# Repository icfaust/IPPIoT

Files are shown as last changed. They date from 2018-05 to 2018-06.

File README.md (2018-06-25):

# IPPIoT
ESP8266 native Non-OS SDK 7-segment JSON number display

This is the necessary documentation for someone to collect the necessary components and compile the right code for
their very own web JSON reader.  Its pretty basic with a hardcoded wifi and website to access for the JSON. 

The components should all work well together, using the CATIA files, EAGLE files, and list of components to create
the device.  If you end up trying to build one, let me know!!!!!

The code does require a successfully installed pfaclon esp-open-sdk installation.  The makefile should work pretty straight-forwardly on a Ubuntu or Linux distro (thats what I used).

You can go over to my personal website for a more in-depth explanation of the design process with photos.

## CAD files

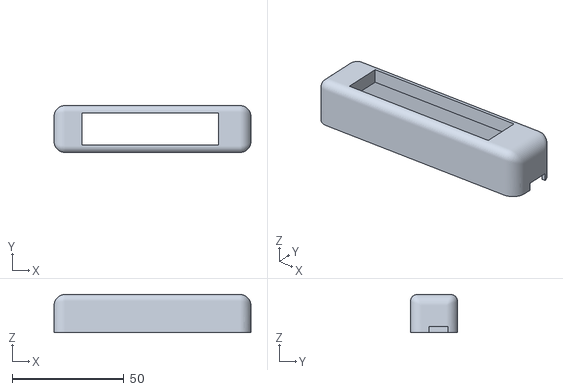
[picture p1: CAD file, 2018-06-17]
CATIA/Top_Housing.stl
88.0 x 21.0 x 17.0

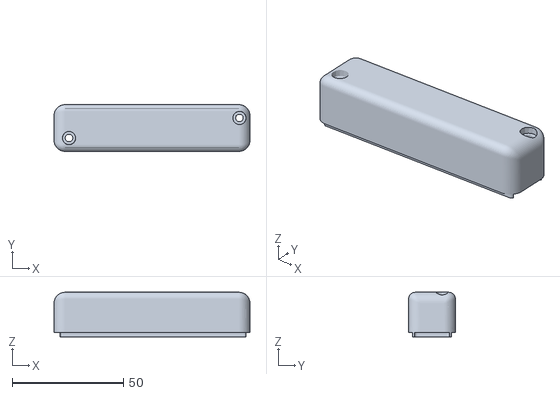
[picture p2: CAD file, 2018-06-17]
CATIA/Back_Housing.stl
88.0 x 21.0 x 20.0

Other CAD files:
CATIA/Back_Housing.CATPart
CATIA/Top_Housing.CATPart

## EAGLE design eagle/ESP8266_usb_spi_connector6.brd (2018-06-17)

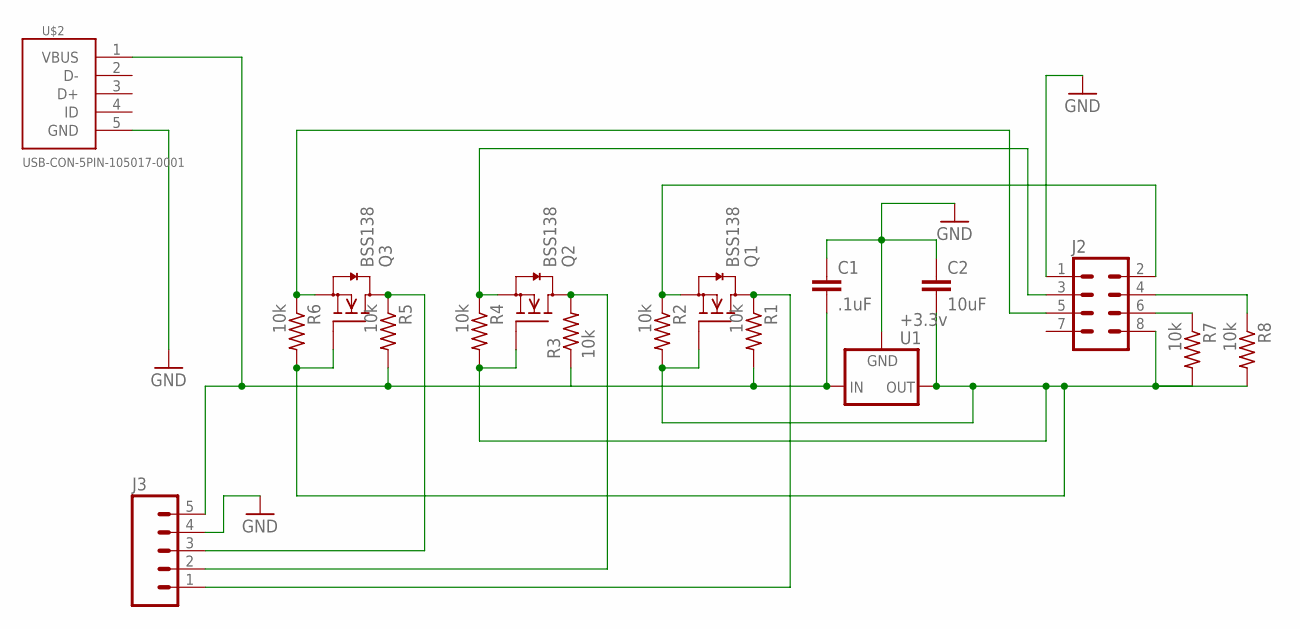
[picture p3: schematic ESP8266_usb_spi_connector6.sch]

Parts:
C1: .1uF; 1206
C2: 10uF; 1206
J2: M04X2; 2X4
J3: M05PTH; 1X05
Q1, Q2, Q3: BSS138; SOT23
R1, R2, R3, R4, R5, R6, R7, R8: 10k; M1206
U1: +3.3v; TO-252
U$2: USB-CON-5PIN-105017-0001; USB-MICRO-MOLEX-105017-0001

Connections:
GND: C1.1, C2.1, J2.1, J3.4, U1.3 (GND), U$2.5 (GND)
unnamed: J3.3, Q3.3 (D), R5.1
unnamed: J2.3, Q2.2 (S), R4.1
unnamed: C2.2, J2.8, Q1.1 (G), Q2.1 (G), Q3.1 (G), R2.2, R4.2, R6.2, R7.2, R8.2, U1.2 (OUT)
unnamed: J3.2, Q2.3 (D), R3.2
unnamed: J3.1, Q1.3 (D), R1.1
unnamed: J2.5, Q3.2 (S), R6.1
unnamed: J2.2, Q1.2 (S), R2.1
unnamed: C1.2, J3.5, R1.2, R3.1, R5.2, U1.1 (IN), U$2.1 (VBUS)
unnamed: J2.6, R7.1
unnamed: J2.4, R8.1

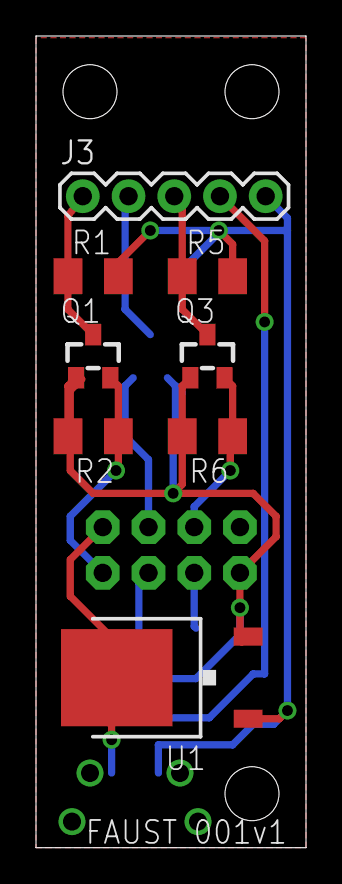
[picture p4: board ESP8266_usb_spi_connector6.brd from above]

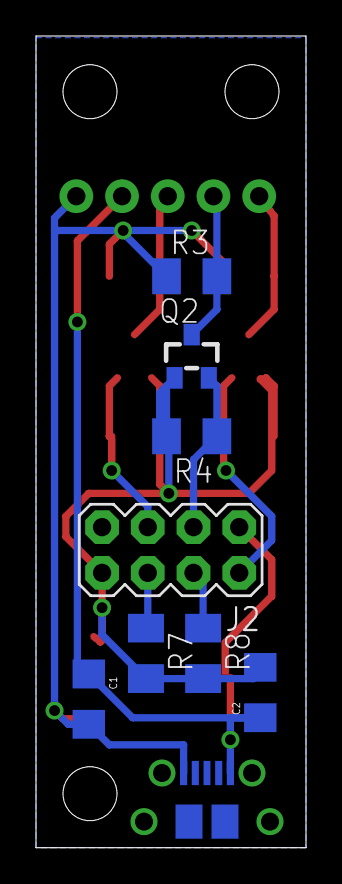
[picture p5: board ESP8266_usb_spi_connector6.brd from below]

Board: 2 copper layers, 15.0 x 45.1 mm, 17 parts (9 on the bottom side), 11 nets.

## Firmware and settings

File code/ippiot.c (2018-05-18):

#include "ets_sys.h"
#include "osapi.h"
#include "gpio.h"
#include "os_type.h"
#include "user_interface.h"
#include "jsonparse.h"

#include "max7221.h"
#include "httpclient.h"

static volatile os_timer_t polling_timer;
static volatile os_timer_t disp_timer;

int inp = 0x01; //intensity metric
int shot = 0;
int hysteresis = 1;

struct jsonparse_state JSONdata;

void ICACHE_FLASH_ATTR dweet_callback(char * response_body, int http_status, char * response_headers, int body_size)
{
  int json_type;
  char string[128];
  int flag = 0;
  jsonparse_setup(&JSONdata, response_body, body_size);
  json_type = jsonparse_next(&JSONdata);

  while(json_type && !flag)
  {
    if(json_type == JSON_TYPE_PAIR_NAME)
      {
	jsonparse_copy_value(&JSONdata, string, 128);
	if(!strcmp("shot", string))
	  {
	    flag = 1;
	  }
      }
    json_type = jsonparse_next(&JSONdata);
  }
  
  if(flag && (json_type == JSON_TYPE_INT || json_type == JSON_TYPE_NUMBER))
    {
      shot = jsonparse_get_value_as_int(&JSONdata);
    }
  else
    {
      shot = 0;
    }
}
  
void ICACHE_FLASH_ATTR scan_intensity(void *args)
{
  printf_max(MAX_INTS,inp);
  //intensity(inp);  
  inp = inp + 1;
  if(inp > 0x0F)
    {
      inp = 0x00;
    }
}

void ICACHE_FLASH_ATTR heartbeat(void *arg)
{
  //function to minimally show that the device is on
  if(inp != 0)
    {
      printf_max(0x01,0x80);
      inp = 0;
    }
  else
    {
      printf_max(0x01,0x00);
      inp = 1;
    }
}

void ICACHE_FLASH_ATTR startup( void *arg)
{
  int i=8;

  if(inp <= 0x01 || inp > 0x40)
  {
    inp = 0x40;
  }
    //function to minimally show that the device is on
  for(;i;i--)
    {
      printf_max(i,inp);
    }
  inp = inp >> 1;
}

void ICACHE_FLASH_ATTR polling(void *arg){

  http_get("https://dweet.io/get/latest/dweet/for/AUGSIF","",dweet_callback);

  if(shot != hysteresis)
    {

      os_timer_disarm(&disp_timer);
      os_timer_disarm(&polling_timer);
      
      if(shot == 0)
	{
	  clear_max();
	  //intensity(0x0F);
	  printf_max(MAX_INTS,0x0F);
	  
	  os_timer_setfn(&disp_timer, (os_timer_func_t *)heartbeat, NULL);
	  os_timer_arm(&disp_timer, 1000, 1);
	  
	  os_timer_setfn(&polling_timer, (os_timer_func_t *)polling, NULL);
	  os_timer_arm(&polling_timer, 600000, 1); // only check every 10 minutes if data in unavailable
	  
	}
      else if(shot < 0)
	{
	  disp_shot_text();
	  //start timer
	  os_timer_setfn(&disp_timer, (os_timer_func_t *)scan_intensity, NULL);
	  os_timer_arm(&disp_timer, 100, 1);
	  
	  os_timer_setfn(&polling_timer, (os_timer_func_t *)polling, NULL);
	  os_timer_arm(&polling_timer, 5000, 1); // check every 5 seconds while in shot cycle
	  
	}
      else
	{
	  //display shot
	  //intensity(0x0F);
	  printf_max(MAX_INTS,0x0F);
	  printf_max_int(shot);
	  
	  os_timer_setfn(&polling_timer, (os_timer_func_t *)polling, NULL);
	  os_timer_arm(&polling_timer, 20000, 1); // check every 20 seconds during runday
	}

      hysteresis = shot;
    }
}

void ICACHE_FLASH_ATTR wifi_handle_event_cb(System_Event_t *evt)
{
  
  switch (evt->event) {
  case EVENT_STAMODE_CONNECTED:
    os_timer_disarm(&disp_timer);
    os_timer_disarm(&polling_timer);
    
    clear_max();
    //intensity(0x0F);
    printf_max(MAX_INTS,0x0F);

    os_timer_setfn(&disp_timer, (os_timer_func_t *)heartbeat, NULL);
    os_timer_arm(&disp_timer, 1000, 1);
    break;
    
  case EVENT_STAMODE_DISCONNECTED:
    os_timer_disarm(&disp_timer);
    os_timer_disarm(&polling_timer);
    
    os_timer_setfn(&disp_timer, (os_timer_func_t *)startup, NULL);
    os_timer_arm(&disp_timer, 100, 1);
    break;
    
  case EVENT_STAMODE_AUTHMODE_CHANGE:
    os_timer_disarm(&disp_timer);
    os_timer_disarm(&polling_timer);
    
    os_timer_setfn(&disp_timer, (os_timer_func_t *)startup, NULL);
    os_timer_arm(&disp_timer, 100, 1);
    break;
    
  case EVENT_STAMODE_GOT_IP:    
    //os_timer_disarm(&polling_timer);
    //os_timer_setfn(&polling_timer, (os_timer_func_t *)polling, NULL);
    //os_timer_arm(&polling_timer, 20000, 1);
    polling(NULL);
    break;
    
  default:
    break;
  }
}

void ICACHE_FLASH_ATTR user_init()
{  
  struct station_config wifi_config;
  // init gpio subsytem
  gpio_init();

  // configure UART TXD to be GPIO1, set as output
  PIN_FUNC_SELECT(PERIPHS_IO_MUX_U0TXD_U, FUNC_GPIO1); 
  /*gpio_output_set(0, BIT2, BIT2, 0);
  gpio_output_set(0, BIT1, BIT1, 0); //OFF
  gpio_output_set(0, BIT0, BIT0, 0);*/

  //gpio_output_set(BIT2, 0, BIT2, 0);
  //gpio_output_set(BIT1, 0, BIT1, 0); //ON
  //gpio_output_set(BIT0, 0, BIT0, 0);
  
  max_init(NULL);

  //printf_max(0x01,0xFF);
  // startup no wifi display animation
  os_timer_disarm(&disp_timer);
  os_timer_setfn(&disp_timer, (os_timer_func_t *)startup, NULL);
  os_timer_arm(&disp_timer, 100, 1);

  wifi_set_opmode(STATION_MODE);
  // set station configuration, save to flash
  os_memset(&wifi_config, 0, sizeof(wifi_config));
  os_memcpy(&wifi_config.ssid, "IPP Guests", os_strlen("IPP Guests"));
  os_memcpy(&wifi_config.password, "", os_strlen(""));
  wifi_station_set_config(&wifi_config);
  
  wifi_set_event_handler_cb(wifi_handle_event_cb);
}

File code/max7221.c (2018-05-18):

#include "ets_sys.h"
#include "osapi.h"
#include "gpio.h"
#include "os_type.h"

#include "max7221.h"

void ICACHE_FLASH_ATTR bit_bang_SPI(int val){
  /* this takes a one byte unsigned char containing two hex values
  // and writes it out to GPIO 
  */
  //unsigned char val = 0xA9;
  
  int test = 0x80;
  int i=0;
  for(;i<8;i++) {
    
    if (val & test)
    {    
    gpio_output_set(BIT0, 0, BIT0, 0); //DIN HIGH (ON)
    }  
    else
    {  
    gpio_output_set(0, BIT0, BIT0, 0); //DIN LOW (OFF)
    }
    os_delay_us(10);


    gpio_output_set(0, BIT1, BIT1, 0); //CLK LOW (OFF)
    os_delay_us(10);    
    gpio_output_set(BIT1, 0, BIT1, 0); //CLK HIGH (ON)
    os_delay_us(10);
    
    val = val << 1;
  }
}


void ICACHE_FLASH_ATTR printf_max(int word1, int word2){
  gpio_output_set(0, BIT2, BIT2, 0); //CS LOW (OFF)
  bit_bang_SPI(word1);
  bit_bang_SPI(word2);
  gpio_output_set(BIT2, 0, BIT2, 0); //CS HIGH (ON) LATCH DATA
  os_delay_us(10);
}


void ICACHE_FLASH_ATTR max_init(void *args){

  os_delay_us(5000);
  printf_max(MAX_DISP, 0xFE); //display normal
  printf_max(MAX_SHUT, 0x01); //shutdown normal
  printf_max(MAX_DECO, 0x00); // put everything in individual control
  printf_max(MAX_SCAN, 0x0F); //scan limit all digits
  //intensity(0x0F); // set high intensity
  printf_max(MAX_INTS, 0x0F);
  clear_max();
  os_delay_us(5000); 
}


void ICACHE_FLASH_ATTR clear_max()
{
  int i=1;
  
  for(;i<9;i++)
    {
      printf_max(i, 0x00);
    }
}


/*void ICACHE_FLASH_ATTR intensity(int val)
{
  printf_max(MAX_INTS, val);
}
*/

void ICACHE_FLASH_ATTR disp_shot_text()
{
  int j=4;
    
  for(;j;j--)
    {
      printf_max(j, 0x00);
    }
  
  printf_max(0x08,MAX_S);
  printf_max(0x07,MAX_H);
  printf_max(0x06,MAX_O);
  printf_max(0x05,MAX_T);
}


void ICACHE_FLASH_ATTR printf_max_int(int val)
{
  // display number
  int max = 10000000;
  int i = 8;
  int j = 1;
  int flag=0;

  // find number of digits to display
  if(val == 0)
    {
      i = 1;
      j = 0;
    }
  else
    {
    if(val < 0)
      {
	flag = 1; // do something with flag later
	val = -1*val;
      }

    while(j)
      {
	if(val/max)
	  {
	    j=0;
	  }
	else
	  {
	    i--;
	    max = max/10;
	  }
      }
    }

  //display digits
  for(;j<i;j++)
    {
      printf_max(j+1, maxnums[val % 10]);
      val = val/10;      
    }
  for(;j<8;j++)
    {
      printf_max(j+1, 0x00);
    }
}

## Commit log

2018-06-17 updates to structure
    [ESP8266_usb_spi_connector.sch, ESP8266_usb_spi_connector2.sch, ESP8266_usb_spi_connector3.sch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]
2018-06-17 added CATIA files for structure
    [Back_Housing.CATPart, Back_Housing.stl, Top_Housing.CATPart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]
2018-06-17 removed redundant files
    [ESP8266_usb_spi_connector2.sch, ESP8266_usb_spi_connector3.sch, ESP8266_usb_spi_connector5.brd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]
2018-06-25 better board spec
    [ESP8266_usb_spi_connector7.GBL, ESP8266_usb_spi_connector7.GBO, ESP8266_usb_spi_connector7.GBP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]
2018-06-25 updated eagle documents
    [ESP8266_usb_spi_connector4.GBL, ESP8266_usb_spi_connector4.GBO, ESP8266_usb_spi_connector4.GBP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]
2018-06-25 further cleaning
    [ESP8266_usb_spi_connector.sch]
2018-06-25 updated files to actual production versions
    [ESP8266_usb_spi_connector6.brd, ESP8266_usb_spi_connector6.sch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]
2018-06-25 added necessary parts list
    [IPPIOT_parts_list.xls]
2018-06-29 mistake on number of 10k resistors
    [IPPIOT_parts_list.xls]

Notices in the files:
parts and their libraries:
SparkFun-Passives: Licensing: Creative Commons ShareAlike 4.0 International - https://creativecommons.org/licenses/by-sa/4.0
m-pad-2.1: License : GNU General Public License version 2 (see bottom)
